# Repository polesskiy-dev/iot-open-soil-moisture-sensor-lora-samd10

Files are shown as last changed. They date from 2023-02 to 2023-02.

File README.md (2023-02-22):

# IoT Soil Moisture Sensor

### Open source, low power, cost-effective, 10 years from 1 LiSOCl2 battery. LoRa communication channel. Supports 2 probes functionality for multi-depth sensoring.

### Based on [Microchip (Atmel) SAMD10 ](https://ww1.microchip.com/downloads/en/DeviceDoc/Atmel-42242-SAM-D10_Datasheet.pdf) chip: ~1.5$, 32bit Cortex M0+

## Features

- LoRa communication
- LiSOCl2 7.7A 26500 battery
- RTC clock
- 2 I2C SHTxx Senserion sensors
- Battery self-measure

## Schematics
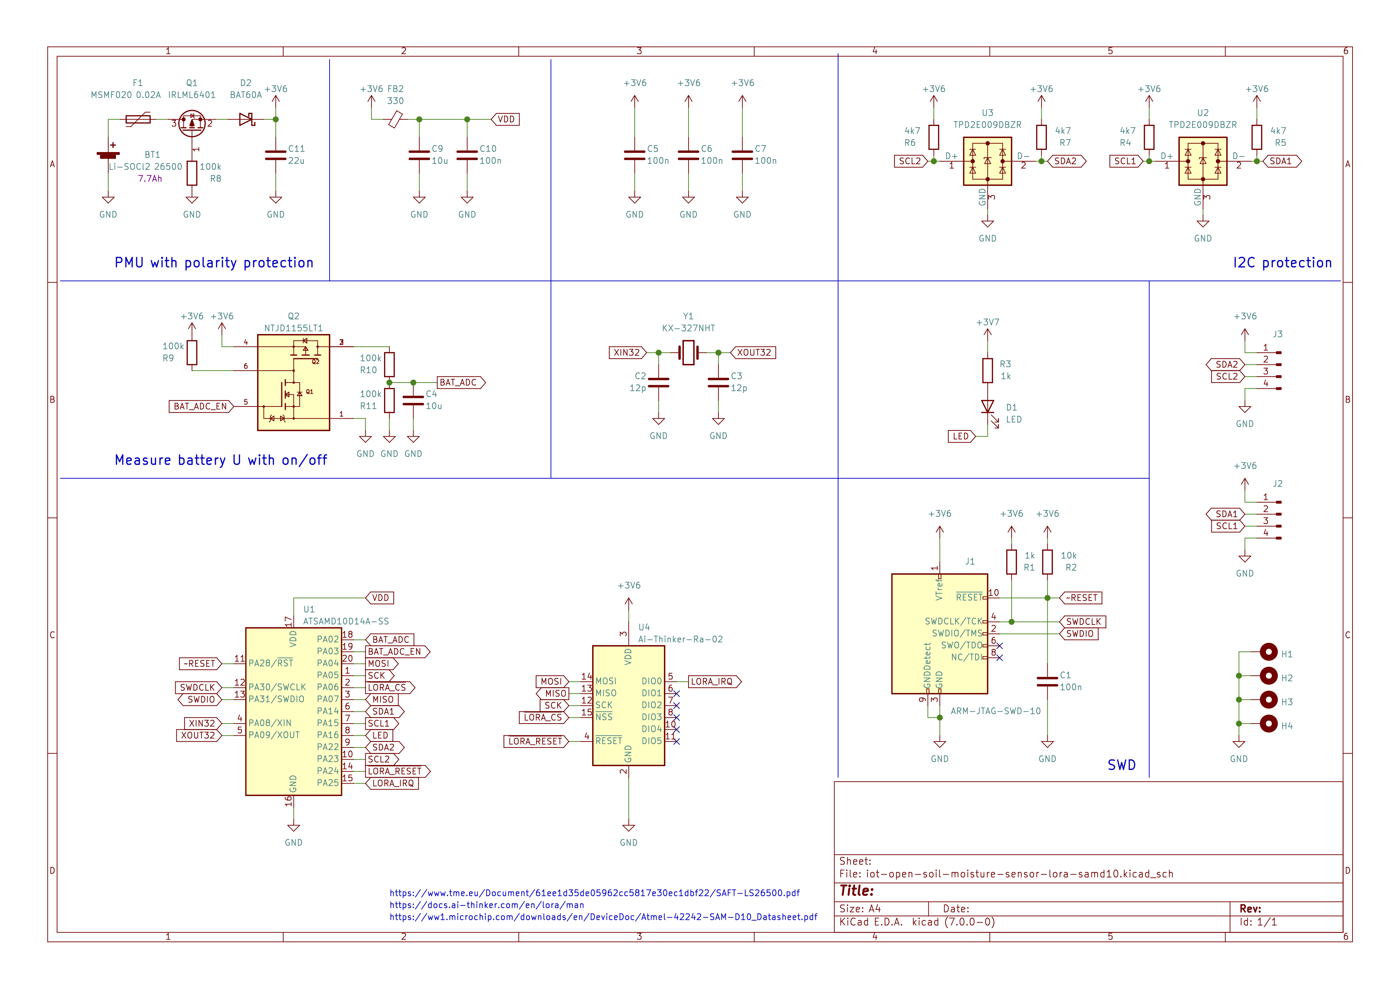
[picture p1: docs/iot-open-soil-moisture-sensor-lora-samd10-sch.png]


## PCB
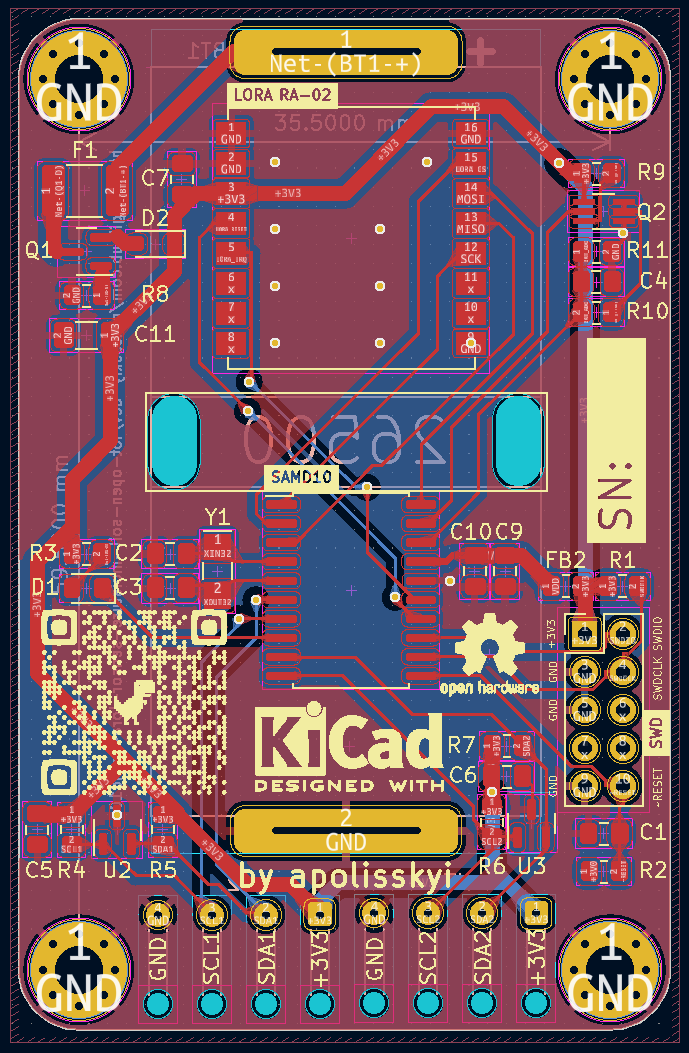
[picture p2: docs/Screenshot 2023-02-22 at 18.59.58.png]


## PCB Renders
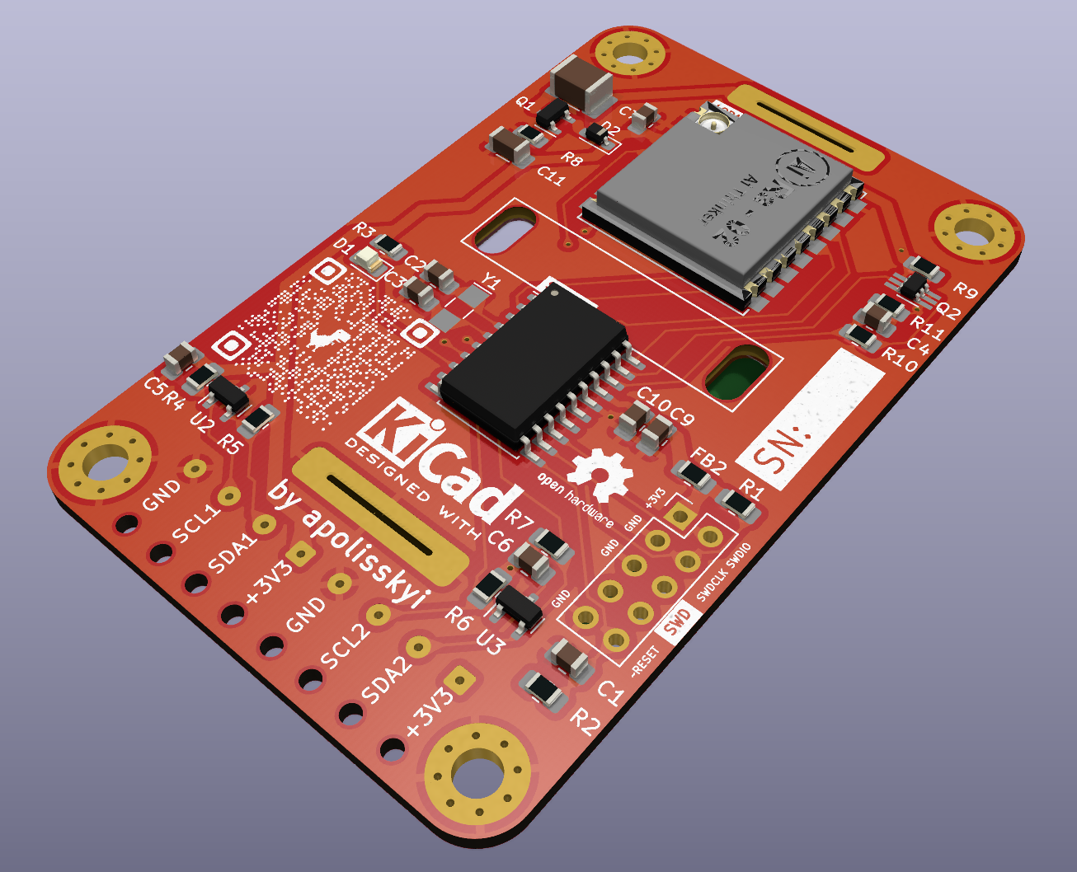
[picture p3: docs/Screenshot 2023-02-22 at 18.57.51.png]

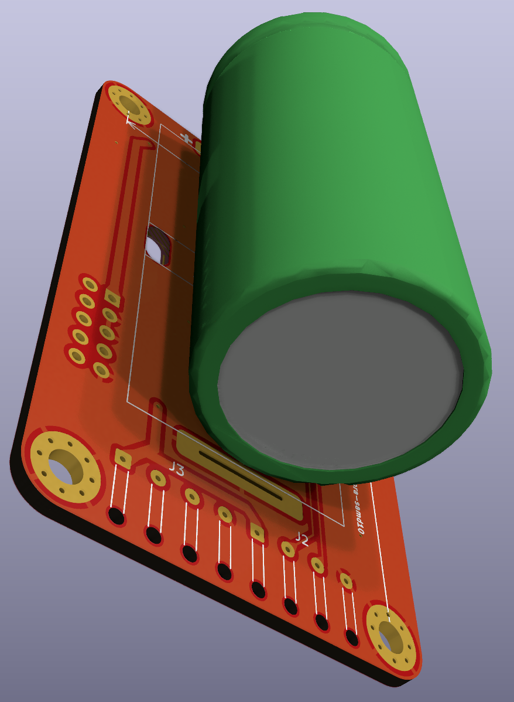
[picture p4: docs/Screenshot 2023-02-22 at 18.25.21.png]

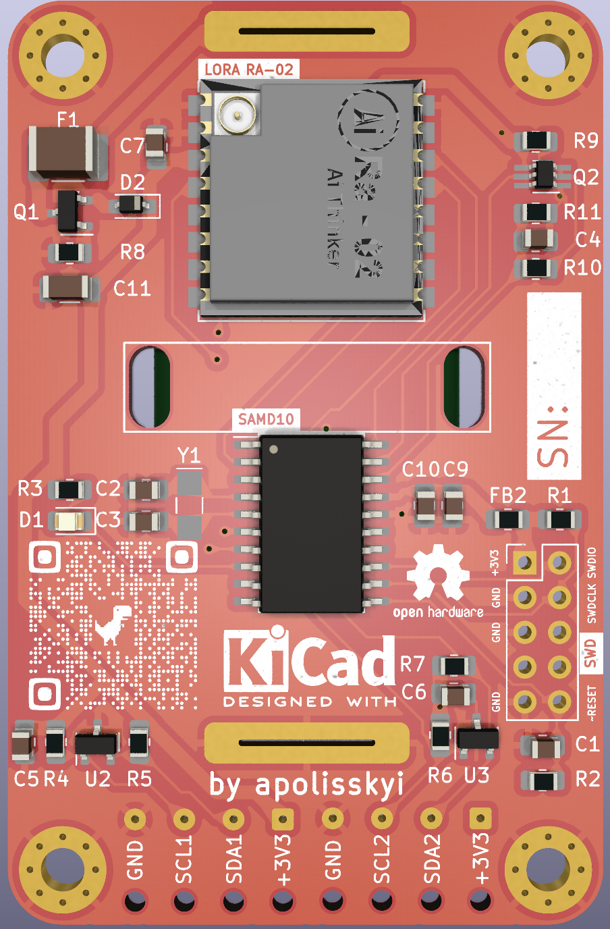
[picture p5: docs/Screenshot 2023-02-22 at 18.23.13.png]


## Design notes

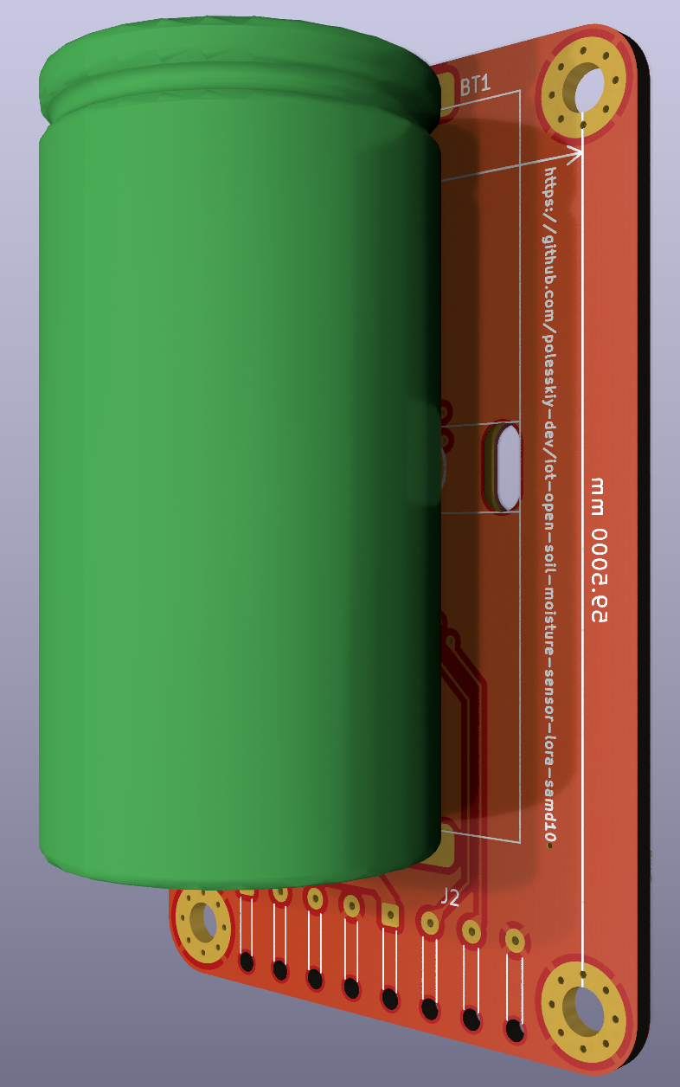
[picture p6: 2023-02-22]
docs/Screenshot 2023-02-22 at 18.24.27.png

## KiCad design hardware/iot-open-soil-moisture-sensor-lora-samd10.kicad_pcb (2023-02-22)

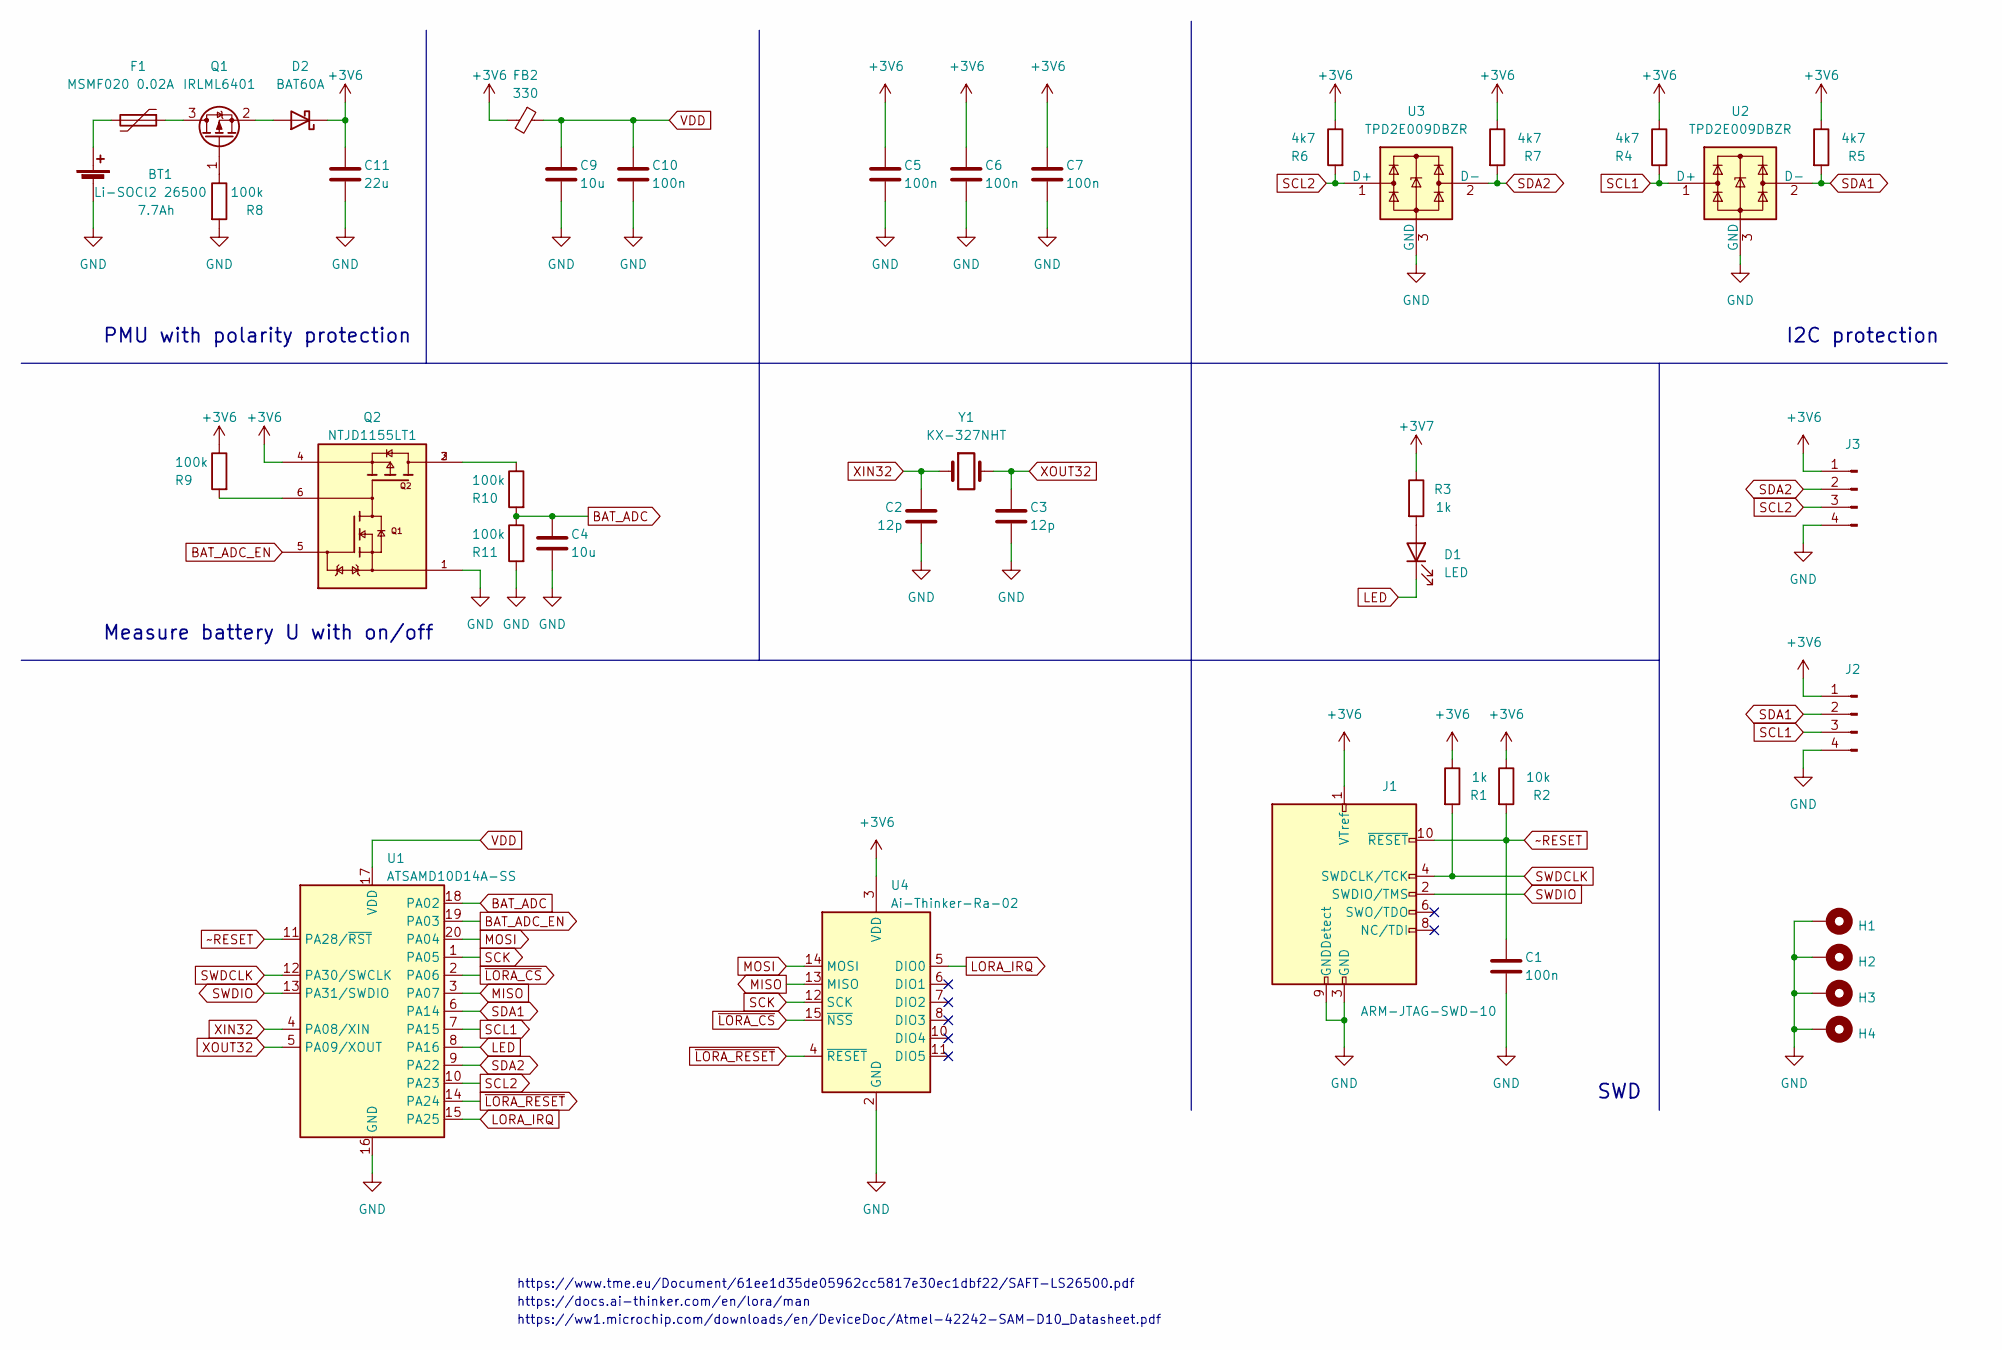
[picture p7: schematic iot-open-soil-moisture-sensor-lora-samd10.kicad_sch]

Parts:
BT1: Li-SOCl2 26500; BAT-26500
C1, C5, C6, C7, C10: 100n; C_0805_2012Metric_Pad1.18x1.45mm_HandSolder
C2, C3: 12p; C_0805_2012Metric_Pad1.18x1.45mm_HandSolder
C4, C9: 10u; C_0805_2012Metric_Pad1.18x1.45mm_HandSolder
C11: 22u; C_1206_3216Metric_Pad1.33x1.80mm_HandSolder
D1: LED; LED_0805_2012Metric_Pad1.15x1.40mm_HandSolder
D2: BAT60A; D_SOD-323_HandSoldering
F1: MSMF020 0.02A; C_1812_4532Metric_Pad1.57x3.40mm_HandSolder
FB2: 330; R_0805_2012Metric_Pad1.20x1.40mm_HandSolder
H1, H2, H3, H4: MountingHole_Pad; MountingHole_3.2mm_M3_Pad_Via
J1: ARM-JTAG-SWD-10; PinHeader_2x05_P2.54mm_Vertical
J2, J3: Conn_01x04_Pin; SolderWire-0.1sqmm_1x04_P3.6mm_D0.4mm_OD1mm_Relief
Q1: IRLML6401; SOT-23
Q2: NTJD1155LT1; SOT-363_SC-70-6_Handsoldering; PARTREV Rev. 6
R1, R3: 1k; R_0805_2012Metric_Pad1.20x1.40mm_HandSolder
R2: 10k; R_0805_2012Metric_Pad1.20x1.40mm_HandSolder
R4, R5, R6, R7: 4k7; R_0805_2012Metric_Pad1.20x1.40mm_HandSolder
R8, R9, R10, R11: 100k; R_0805_2012Metric_Pad1.20x1.40mm_HandSolder
U1: ATSAMD10D14A-SS; SOIC-20W_7.5x12.8mm_P1.27mm
U2, U3: TPD2E009DBZR; SOT-23
U4: Ai-Thinker-Ra-02; Ai-Thinker-Ra-01-LoRa
Y1: KX-327NHT; Crystal_SMD_EuroQuartz_EQ161-2Pin_3.2x1.5mm_HandSoldering

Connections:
BAT_ADC: C4.1, R10.2, R11.1; also elsewhere on the board
BAT_ADC_EN: Q2.5, U1.19 (PA03); also elsewhere on the board
GND: BT1.2 (-), C1.2, C2.2, C3.2, C4.2, C5.2, C6.2, C7.2, C9.2, C10.2, C11.2, H1.1, H2.1, H3.1, H4.1, J2.4, J3.4, Q2.1, R8.2, R11.2, U2.3 (GND), U3.3 (GND); also elsewhere on the board
LED: D1.1 (K); also elsewhere on the board
unnamed: BT1.1 (+), F1.2
unnamed: D1.2 (A), R3.2
unnamed: D2.2 (A), Q1.2 (S)
unnamed: J1.2 (SWDIO/TMS), U1.13 (PA31/SWDIO)
unnamed: F1.1, Q1.3 (D)
unnamed: Q1.1 (G), R8.1
unnamed: Q2.2, Q2.3, R10.1
unnamed: Q2.6, R9.2
unnamed: U1.1 (PA05), U4.12 (SCK)
unnamed: U1.2 (PA06), U4.15 (~NSS)
unnamed: U1.3 (PA07), U4.13 (MISO)
unnamed: U1.14 (PA24), U4.4 (~RESET)
unnamed: U1.15 (PA25), U4.5 (DIO0)
unnamed: U1.20 (PA04), U4.14 (MOSI)
SCL1: J2.3, R4.2, U2.1 (D+); also elsewhere on the board
SCL2: J3.3, R6.2, U3.1 (D+); also elsewhere on the board
SDA1: J2.2, R5.2, U2.2 (D-); also elsewhere on the board
SDA2: J3.2, R7.2, U3.2 (D-); also elsewhere on the board
SWDCLK: R1.2; also elsewhere on the board
VDD: C9.1, C10.1, FB2.1; also elsewhere on the board
XIN32: C2.1, Y1.1; also elsewhere on the board
XOUT32: C3.1, Y1.2; also elsewhere on the board
~RESET: C1.1, R2.2; also elsewhere on the board

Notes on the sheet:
https://ww1.microchip.com/downloads/en/DeviceDoc/Atmel-42242-SAM-D10_Datasheet.pdf
PMU with polarity protection
SWD
I2C protection
https://www.tme.eu/Document/61ee1d35de05962cc5817e30ec1dbf22/SAFT-LS26500.pdf
https://docs.ai-thinker.com/en/lora/man
Measure battery U with on/off

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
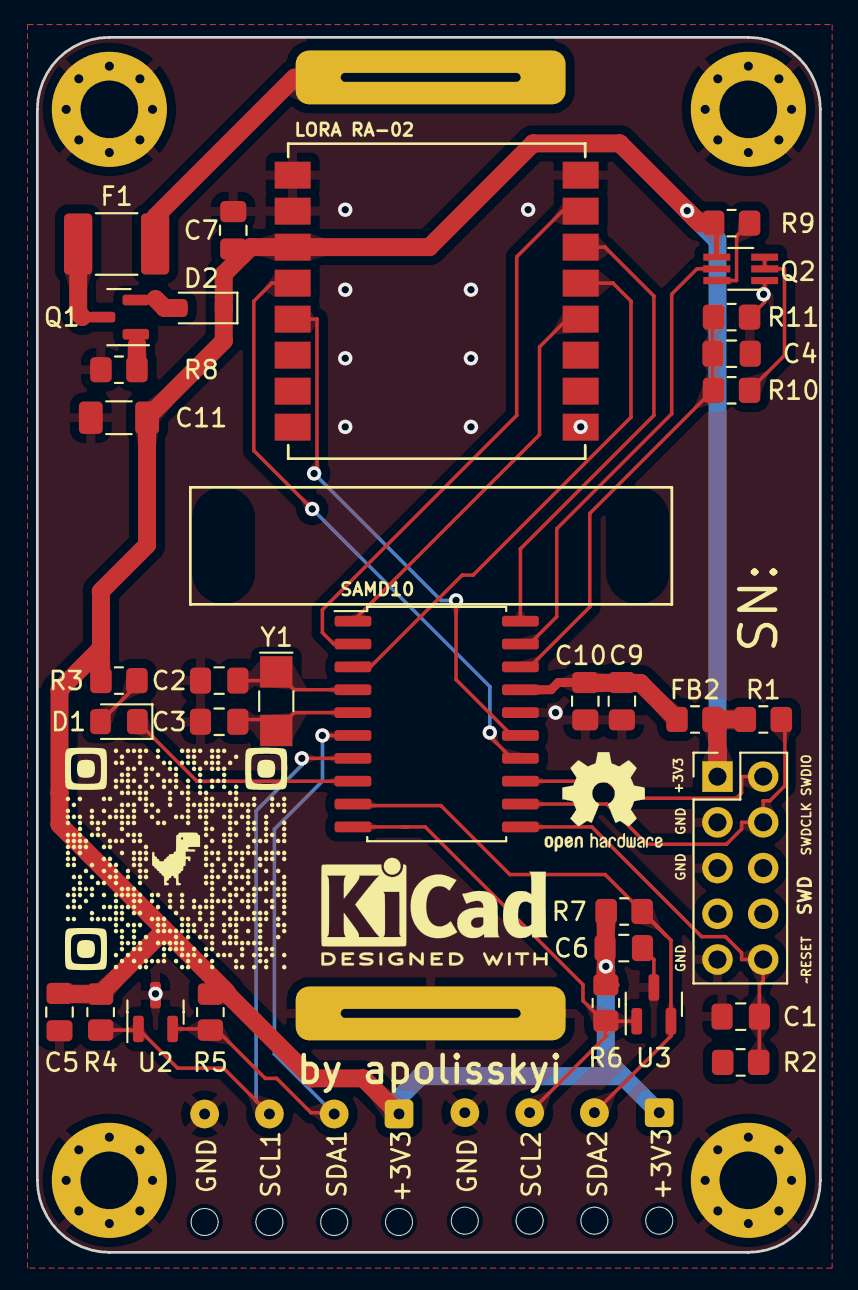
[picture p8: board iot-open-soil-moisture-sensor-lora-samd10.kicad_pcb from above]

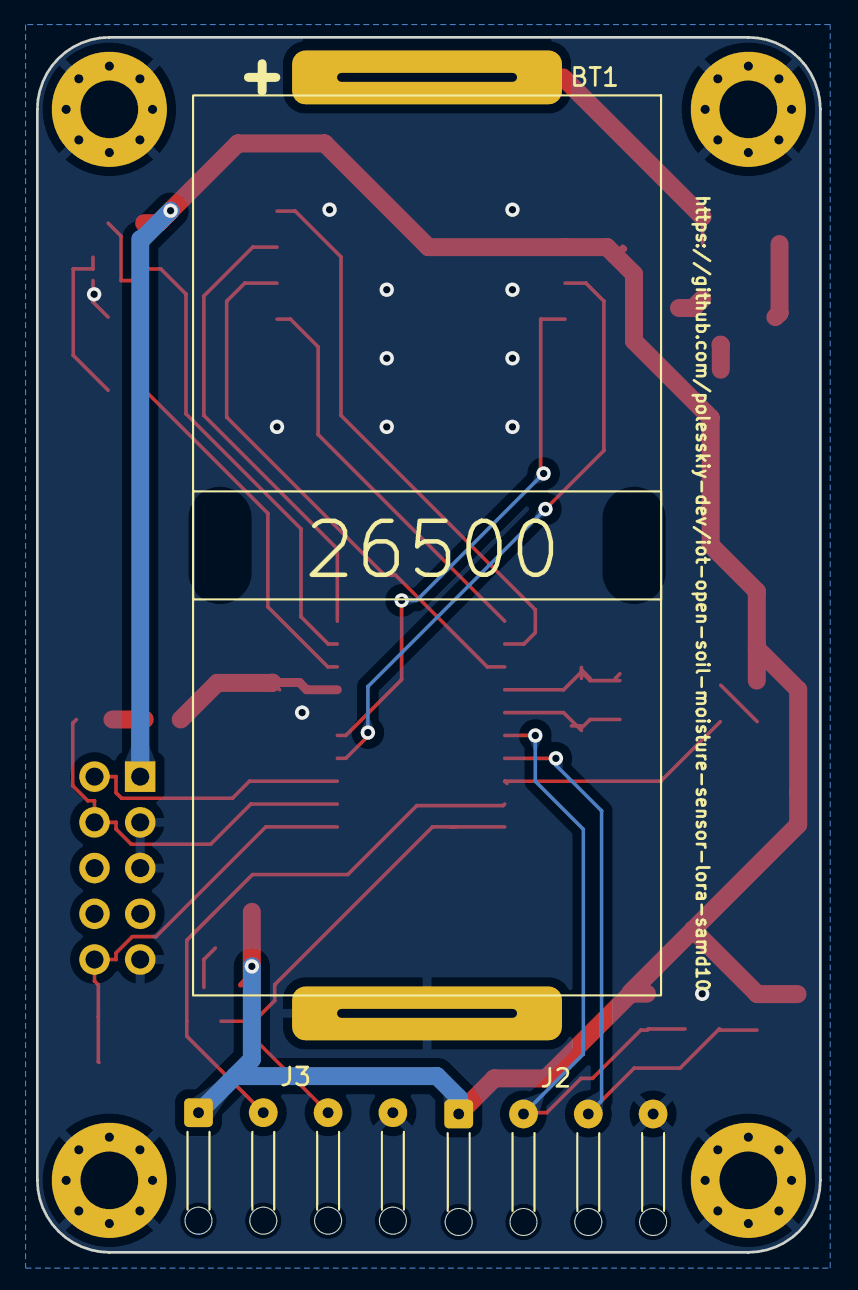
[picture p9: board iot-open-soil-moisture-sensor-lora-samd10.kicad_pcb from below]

Board: 2 copper layers, 43.5 x 67.5 mm, 40 parts (3 on the bottom side), 28 nets.

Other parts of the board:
LORA RA-02: Ai-Thinker-Ra-02; Ai-Thinker-Ra-01-LoRa
SAMD10: ATSAMD10D14A-SS; SOIC-20W_7.5x12.8mm_P1.27mm
SWD: ARM-JTAG-SWD-10; PinHeader_2x05_P2.54mm_Vertical

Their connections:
BAT_ADC: SAMD10.18 (PA02); also elsewhere on the board
BAT_ADC_EN: SAMD10.19 (PA03); also elsewhere on the board
GND: LORA RA-02.1 (GND), LORA RA-02.2 (GND), LORA RA-02.9 (GND), LORA RA-02.16 (GND), SAMD10.16 (GND), SWD.3 (GND), SWD.5 (GND), SWD.9 (GNDDetect); also elsewhere on the board
LED: SAMD10.8 (PA16); also elsewhere on the board
LORA_IRQ: LORA RA-02.5 (DIO0), SAMD10.15 (PA25)
MISO: LORA RA-02.13 (MISO), SAMD10.3 (PA07)
MOSI: LORA RA-02.14 (MOSI), SAMD10.20 (PA04)
SCK: LORA RA-02.12 (SCK), SAMD10.1 (PA05)
SCL1: SAMD10.7 (PA15); also elsewhere on the board
SCL2: SAMD10.10 (PA23); also elsewhere on the board
SDA1: SAMD10.6 (PA14); also elsewhere on the board
SDA2: SAMD10.9 (PA22); also elsewhere on the board
SWDCLK: SAMD10.12 (PA30/SWCLK), SWD.4 (SWDCLK/TCK); also elsewhere on the board
SWDIO: SAMD10.13 (PA31/SWDIO), SWD.2 (SWDIO/TMS)
VDD: SAMD10.17 (VDD); also elsewhere on the board
XIN32: SAMD10.4 (PA08/XIN); also elsewhere on the board
XOUT32: SAMD10.5 (PA09/XOUT); also elsewhere on the board
~RESET: SAMD10.11 (PA28/~RST), SWD.10 (~RESET); also elsewhere on the board
~LORA_CS: LORA RA-02.15 (~NSS), SAMD10.2 (PA06)
~LORA_RESET: LORA RA-02.4 (~RESET), SAMD10.14 (PA24)

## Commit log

2023-02-19 create schematics first revision
    [iot-open-soil-moisture-sensor-lora-samd10.kicad_pcb, iot-open-soil-moisture-sensor-lora-samd10.kicad_sch]
2023-02-20 create PCB first revision
    [iot-open-soil-moisture-sensor-lora-samd10.kicad_pcb]
2023-02-22 add PCB signs
    [iot-open-soil-moisture-sensor-lora-samd10.dsn, iot-open-soil-moisture-sensor-lora-samd10.kicad_pcb, iot-open-soil-moisture-sensor-lora-samd10.kicad_sch]
2023-02-22 add initial documentation
    [iot-open-soil-moisture-sensor-lora-samd10.kicad_pcb]
